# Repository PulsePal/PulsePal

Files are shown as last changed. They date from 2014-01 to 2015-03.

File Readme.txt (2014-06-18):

This is the official repository for Pulse Pal.

Pulse Pal is an open source instrument, released into the public domain under the GNU public license version 3 (see LICENSE.txt).

IMPORTANT: This license means that you can build and modify the device for your own use and even release derivative works commercially, but all derivative versions of the software and hardware MUST remain open source under the GNU license. If you take our code and design files from this repository and sell a derivative design as a closed source commercial product, we will happily sue you.

This repository contains:
-Firmware (written in Arduino / LeafLabs Maple)
-Software APIs in MATLAB, Python and C++
-Drivers (for Windows - none needed for MAC or Linux)
-Design files for the circuit board
-Design files for the enclosure

Documentation is provided online at: 
https://sites.google.com/site/pulsepalwiki/home

The online documentation contains:

-Ordering and assembly guide
-Installation guide
-Programming guides
-Parameter guide
-Serial interface documentation

Please contact us with any questions, bugs, and general feedback:

Joshua Sanders
sanders@cshl.edu

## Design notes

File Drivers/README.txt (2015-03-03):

This driver package for maple was published as part of the open source Arduino_STM32 repository by Roger Clark.
It was inherited in its entirety to provide simple Windows 7, 8 and 8.1 support for Pulse Pal.
To install the drivers, run /PulsePal/drivers/install_drivers.bat.

See more here:
https://github.com/rogerclarkmelbourne

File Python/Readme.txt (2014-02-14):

Note: The PulsePal Python API currently supports Python 2.X only.

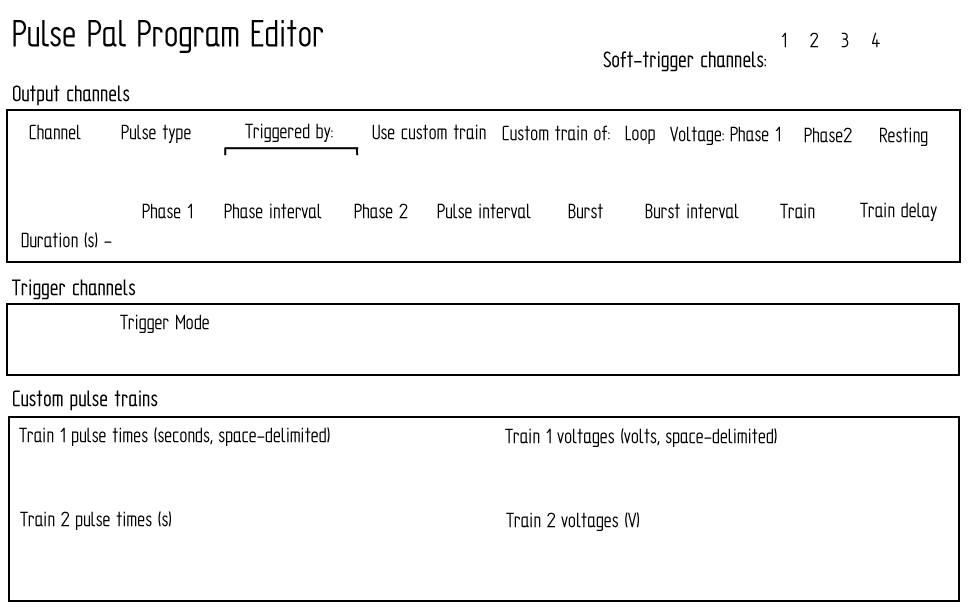
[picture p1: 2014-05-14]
MATLAB/Media/ProgrammerBG.bmp

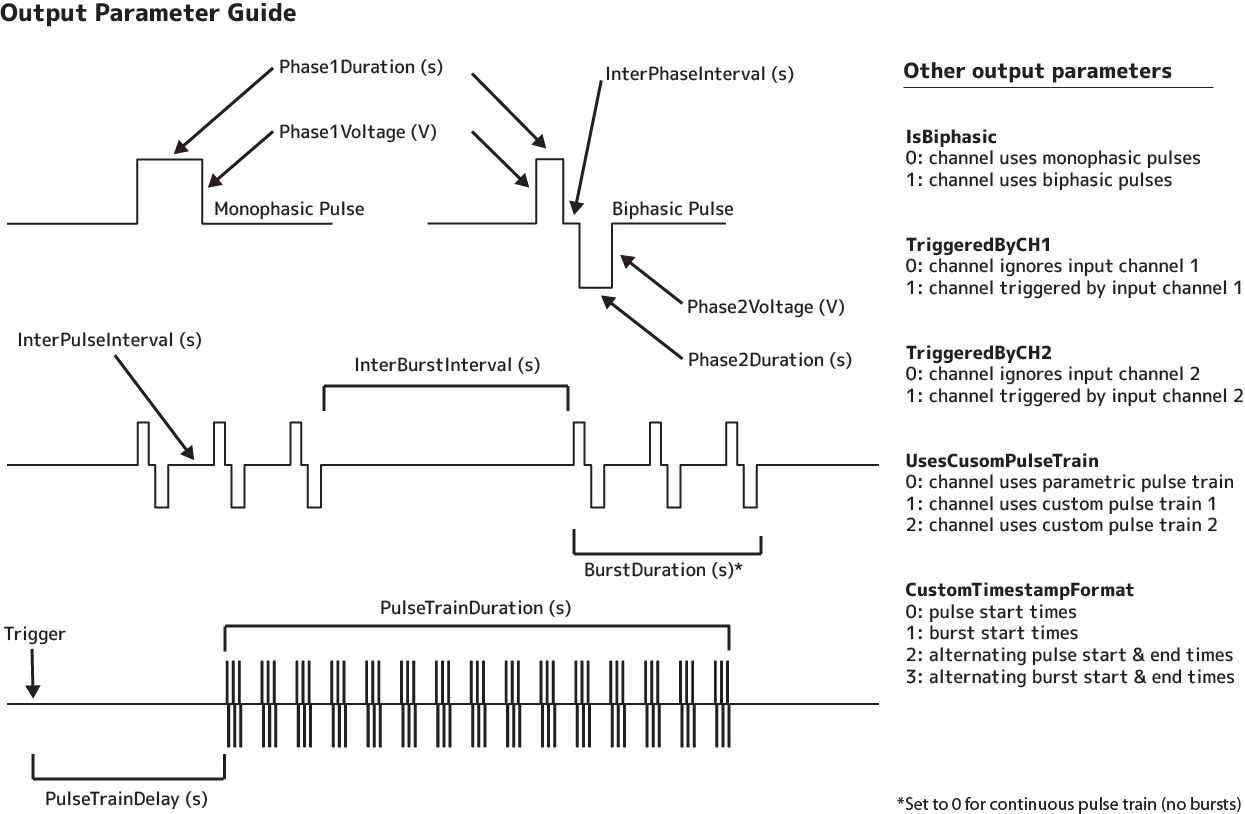
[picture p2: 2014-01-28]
MATLAB/Media/OutputParameterExamples.bmp

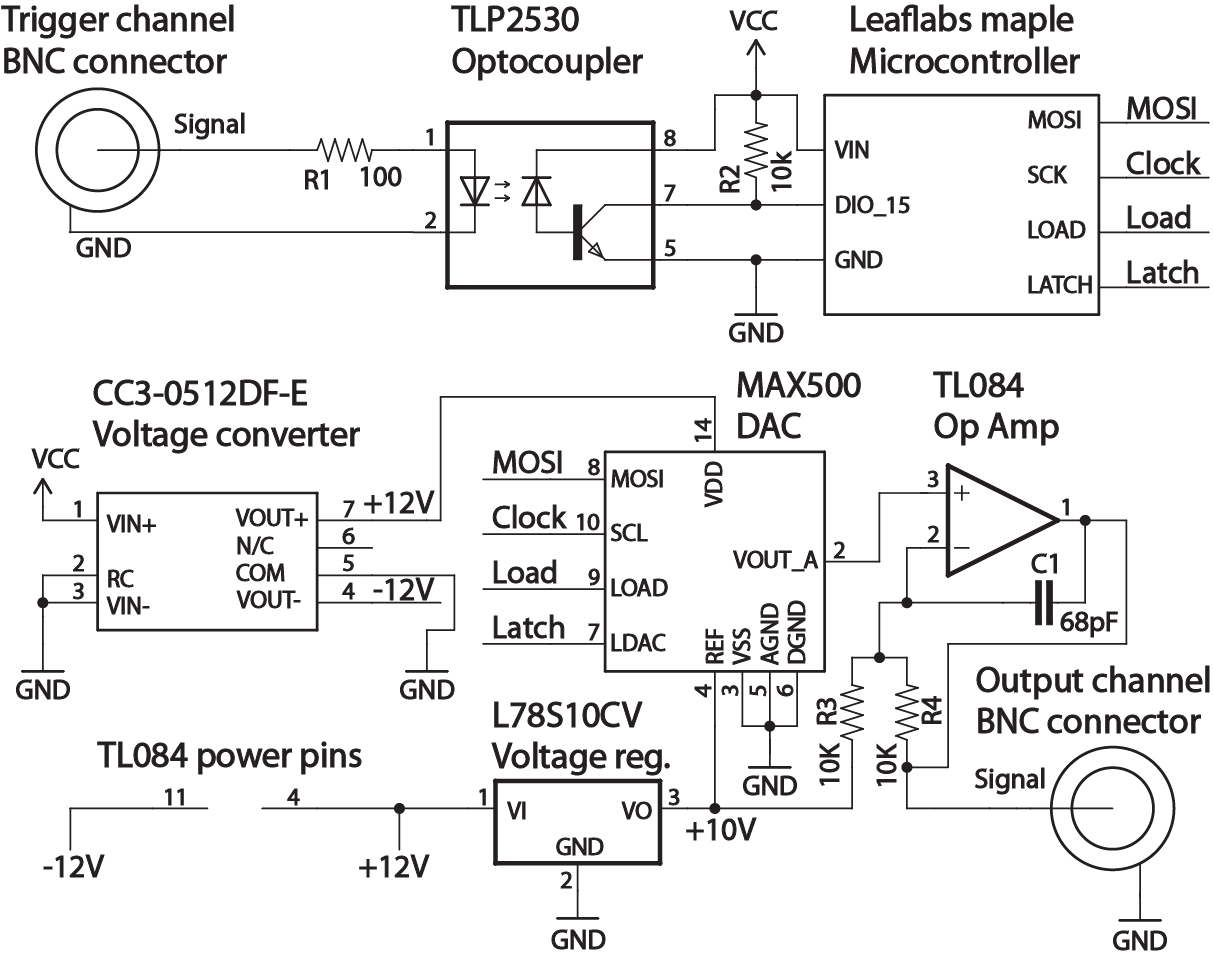
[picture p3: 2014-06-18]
CAD/PCB/r1_0/Essential io circuit.png

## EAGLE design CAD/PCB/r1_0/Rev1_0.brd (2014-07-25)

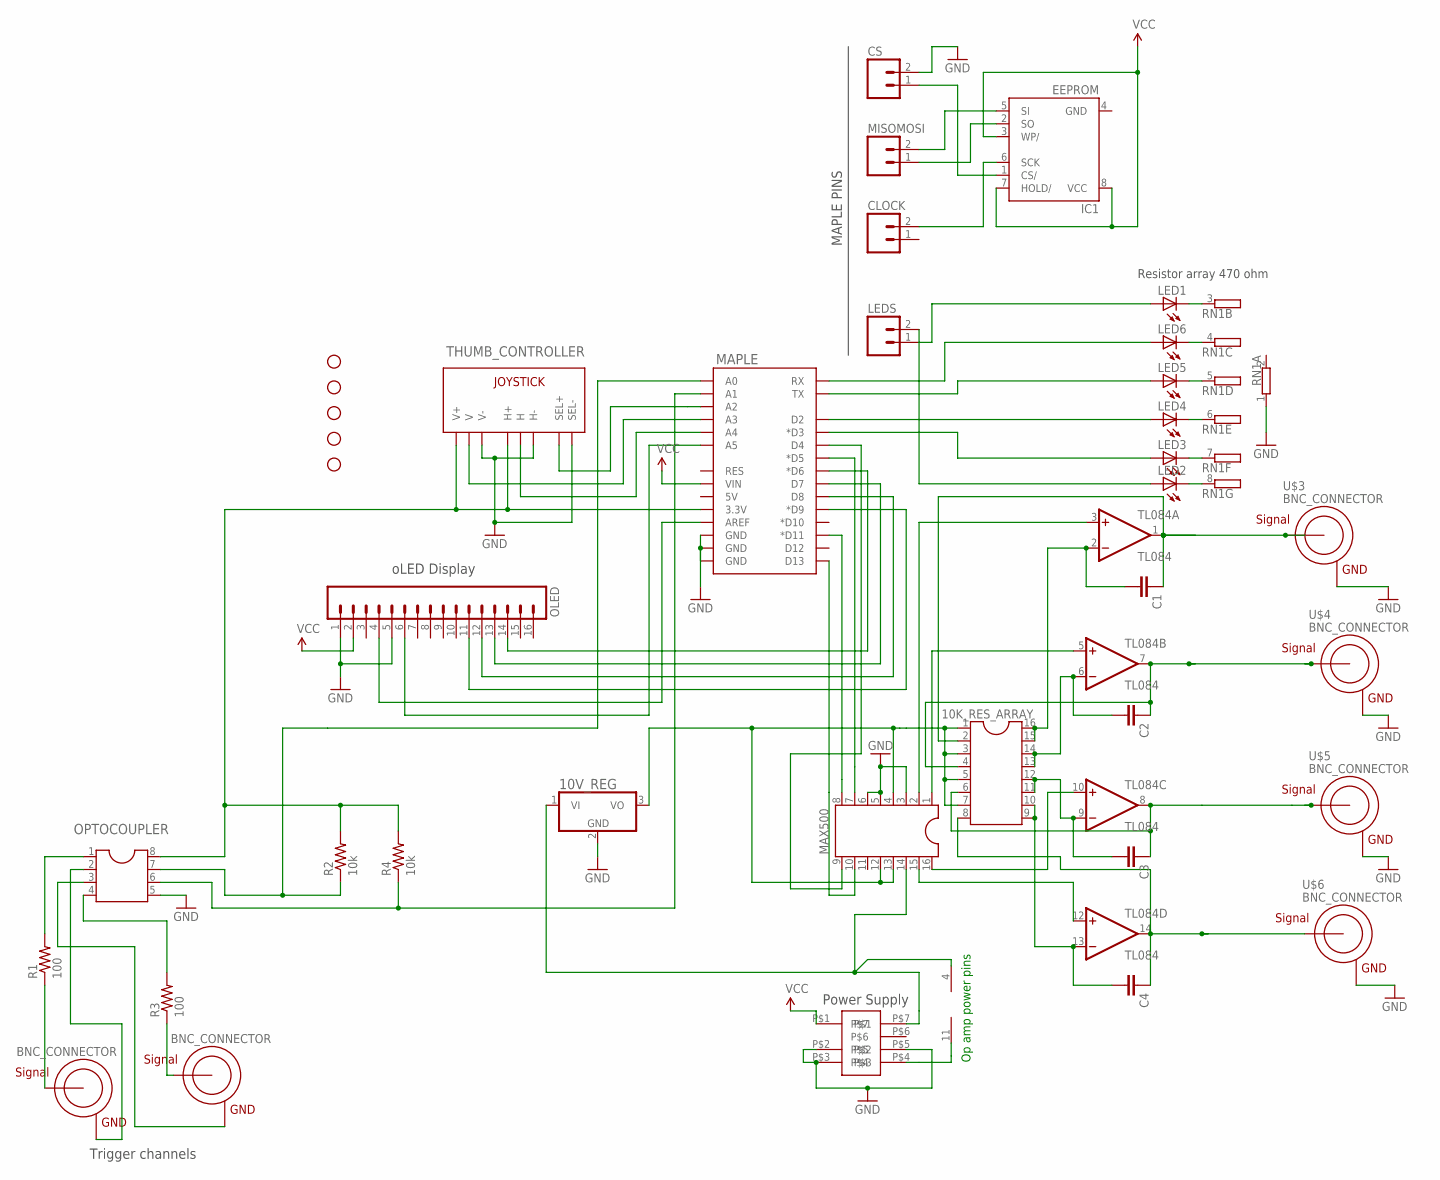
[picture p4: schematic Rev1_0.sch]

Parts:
10K_RES_ARRAY: DIL16
10V_REG: 7805T; TO220H
C1, C2, C3, C4: CAPPTH; CAP-PTH-SMALL
CLOCK: M02PTH; 1X02
CS: M02PTH; 1X02
IC1: EEPROM; DIL08
JP2, JP5, JP6, JP8, JP9: STAND-OFF
LED1, LED2, LED3, LED4, LED5, LED6: LED3MM
LEDS: M02PTH; 1X02
MAPLE: ARDUINO_SHIELDNOHOLESORLABELS; DUEMILANOVE_SHIELD_NOHOLES_NOLABELS
MAX500: DIL16
MISOMOSI: M02PTH; 1X02
OLED: M16PTH; 1X16
OPTOCOUPLER: DIL8; DIL08
R1, R3: 100; AXIAL-0.3
R2, R4: 10k; AXIAL-0.3
RN1: GE07R; SIL8
THUMB_CONTROLLER: JOYSTICKPTH; JOYSTICK
TL084: TL084; DIL14
U$1, U$2, U$3, U$4, U$5, U$6: BNC_CONNECTOR
U$8: TDK_LAMBDA_5_TO_BI_12_125MA

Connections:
GND: 10V_REG.2 (GND), CS.2, IC1.4 (GND), MAPLE.GND@0 (GND), MAPLE.GND@1 (GND), MAPLE.GND@2 (GND), MAX500.3, MAX500.5, MAX500.6, OLED.1, OLED.5, OPTOCOUPLER.5, RN1.1, THUMB_CONTROLLER.B2A (SEL-), THUMB_CONTROLLER.H3 (H-), THUMB_CONTROLLER.V3 (V-), U$3.GND, U$4.GND, U$5.GND, U$6.GND, U$8.P$2, U$8.P$3, U$8.P$5
unnamed: LED6.A, MAPLE.RX
unnamed: LED5.A, MAPLE.TX
unnamed: LED4.A, MAPLE.D2
unnamed: LED3.A, MAPLE.D3 (*D3)
unnamed: MAPLE.D11 (*D11), MAX500.8
unnamed: MAPLE.D13, MAX500.10
unnamed: MAPLE.AREF, OLED.4
unnamed: MAPLE.D4, MAX500.9
unnamed: MAPLE.D5 (*D5), MAX500.7
unnamed: MAPLE.D6 (*D6), OLED.14
unnamed: MAPLE.D7, OLED.13
unnamed: MAPLE.D8, OLED.12
unnamed: MAPLE.D9 (*D9), OLED.11
unnamed: MAPLE.A5, OLED.6
unnamed: MAPLE.A4, THUMB_CONTROLLER.H2 (H)
unnamed: MAPLE.A3, THUMB_CONTROLLER.V2 (V)
unnamed: MAPLE.A2, THUMB_CONTROLLER.B1A (SEL+)
unnamed: R1.P$1 (1), U$1.SIGNAL
unnamed: MAPLE.A0, OPTOCOUPLER.7, R2.P$1 (1)
unnamed: R3.P$1 (1), U$2.SIGNAL
unnamed: MAPLE.A1, OPTOCOUPLER.6, R4.P$1 (1)
unnamed: TL084.11 (V-), U$8.P$4
unnamed: MAX500.2, TL084.3 (+IN)
unnamed: MAX500.1, TL084.5 (+IN)
unnamed: 10V_REG.1 (VI), MAX500.14, TL084.4 (V+), U$8.P$7
unnamed: 10K_RES_ARRAY.1, 10K_RES_ARRAY.3, 10K_RES_ARRAY.5, 10K_RES_ARRAY.7, 10V_REG.3 (VO), MAX500.4, MAX500.12, MAX500.13
unnamed: MAX500.16, TL084.10 (+IN)
unnamed: MAX500.15, TL084.12 (+IN)
unnamed: 10K_RES_ARRAY.2, C1.1, TL084.1 (OUT), U$3.SIGNAL
unnamed: 10K_RES_ARRAY.4, C2.1, TL084.7 (OUT), U$4.SIGNAL
unnamed: 10K_RES_ARRAY.6, C3.1, TL084.8 (OUT), U$5.SIGNAL
unnamed: 10K_RES_ARRAY.8, C4.1, TL084.14 (OUT), U$6.SIGNAL
unnamed: LED1.A, LEDS.1
unnamed: LED2.A, LEDS.2
unnamed: LED2.K (C), RN1.8 (2)
unnamed: LED3.K (C), RN1.7 (2)
unnamed: LED4.K (C), RN1.6 (2)
unnamed: LED5.K (C), RN1.5 (2)
unnamed: LED6.K (C), RN1.4 (2)
unnamed: 10K_RES_ARRAY.15, 10K_RES_ARRAY.16, C1.2, TL084.2 (-IN)
unnamed: 10K_RES_ARRAY.13, 10K_RES_ARRAY.14, C2.2, TL084.6 (-IN)
unnamed: 10K_RES_ARRAY.11, 10K_RES_ARRAY.12, C3.2, TL084.9 (-IN)
unnamed: 10K_RES_ARRAY.9, 10K_RES_ARRAY.10, C4.2, TL084.13 (-IN)
unnamed: LED1.K (C), RN1.3 (2)
unnamed: OPTOCOUPLER.1, R1.P$2 (2)
unnamed: CS.1, IC1.1 (CS/)
unnamed: IC1.5 (SI), MISOMOSI.2
unnamed: IC1.2 (SO), MISOMOSI.1
unnamed: CLOCK.2, IC1.6 (SCK)
unnamed: OPTOCOUPLER.2, U$1.GND
unnamed: OPTOCOUPLER.4, R3.P$2 (2)
unnamed: OPTOCOUPLER.3, U$2.GND
unnamed: MAPLE.3.3V, OPTOCOUPLER.8, R2.P$2 (2), R4.P$2 (2), THUMB_CONTROLLER.H1 (H+), THUMB_CONTROLLER.V1 (V+)
VCC: IC1.3 (WP/), IC1.7 (HOLD/), IC1.8 (VCC), MAPLE.VIN, OLED.2, U$8.P$1

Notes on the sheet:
oLED Display
Power Supply
Op amp power pins
MAPLE PINS
Trigger channels
Resistor array 470 ohm

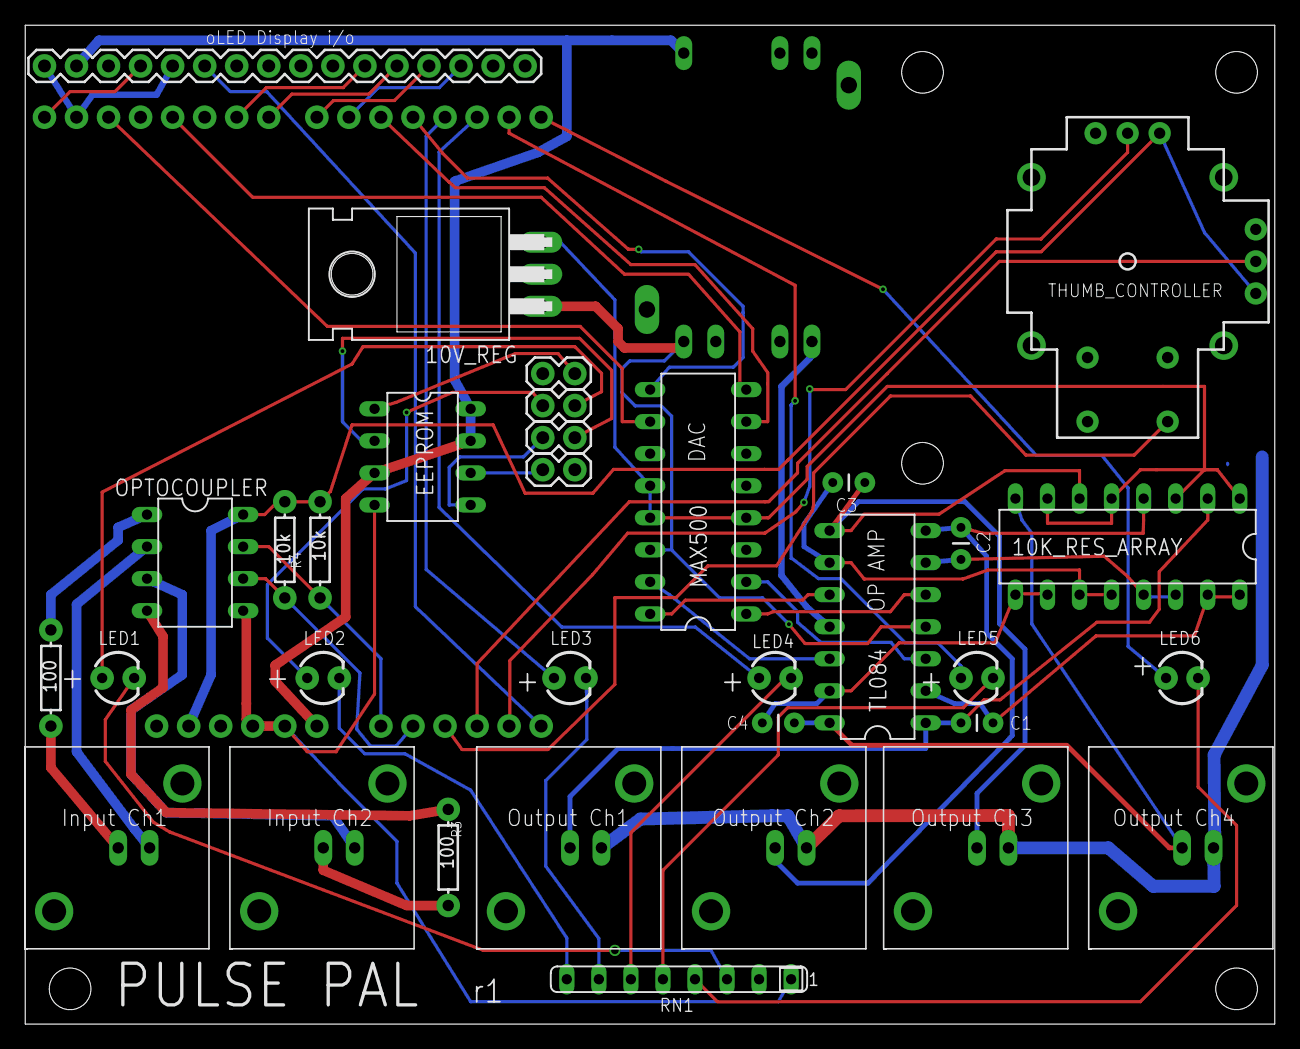
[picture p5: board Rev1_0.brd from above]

Board: 4 copper layers, 99.0 x 79.2 mm, 40 parts (1 on the bottom side), 55 nets.

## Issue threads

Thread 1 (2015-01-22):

Rev1_0_SeeedStudio.zip missing PCB outline file

ksalehi, 2015-01-22:

PulsePal, 2016-01-18:
It should work now.

Closed 2016-01-18.

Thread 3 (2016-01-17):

abort button in matlab GUI

lepmik, 2016-01-17:
It would be nice to be able to stop the current pulse train

PulsePal, 2016-01-18:
You have 4 options for stopping the ongoing pulse train:

1. (stand-alone mode) click the thumb joystick at any time
2. (MATLAB): https://sites.google.com/site/pulsepalwiki/using-pulse-pal/functions/abortpulsepal
3. (Python): https://sites.google.com/site/pulsepalwiki/user-guide---python/python-methods/abortpulsetrains
4: (C++): https://sites.google.com/site/pulsepalwiki/user-guide---c-api/c-methods/abortpulsetrains

Closed 2016-01-18.

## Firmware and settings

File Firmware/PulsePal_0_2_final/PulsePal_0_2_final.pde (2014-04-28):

/*
----------------------------------------------------------------------------

This file is part of the PulsePal Project
Copyright (C) 2014 Joshua I. Sanders, Cold Spring Harbor Laboratory, NY, USA

----------------------------------------------------------------------------

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
*/

// PULSE PAL v0.4 firmware 
// Josh Sanders, March 2012

#include <LiquidCrystal.h>
#include <stdio.h>
#include <gpio.h>

// Define a macro for compressing sequential bytes read from the serial port into long ints
#define makeLong(msb, byte2, byte3, lsb) ((msb << 24) | (byte2 << 16) | (byte3 << 8) | (lsb))
#define LED_PIN_PORT GPIOA
#define INPUT_PIN_PORT GPIOC
// EEPROM constants
#define PAGE_SIZE 32
#define SPI_MODE 0
#define CS 37 // chip select pin
// EEPROM opcodes
#define WREN 6
#define WRDI 4
#define RDSR 5
#define WRSR 1
#define READ 3
#define WRITE 2

// Reset macros
#define SCB_AIRCR ((volatile uint32*) (0xE000ED00 + 0x0C))
#define SCB_AIRCR_SYSRESETREQ (1 << 2)
#define SCB_AIRCR_RESET ((0x05FA0000) | SCB_AIRCR_SYSRESETREQ)

// Trigger line level configuration (0 = default high, trigger low (versions with optocoupler). 1 = default low, trigger high.)
#define TriggerLevel 1
#define ClickerButtonLogicHigh 1


// Firmware build number
unsigned long FirmwareVersion = 2;

// initialize LCD library with the numbers of the interface pins
// Pins matched with hello world LCD sketch
//LiquidCrystal lcd(12, 13, 28, 29, 30, 31);
LiquidCrystal lcd(14, 20, 9, 8, 7, 6);

// Variables that define system parameters
byte InputLines[2] = {15,16};
byte InputLineBits[2] = {0,1};
byte OutputLEDLines[4] = {3,2,1,0}; // Output lines
byte OutputLEDLineBits[4] = {1, 0, 2, 3 }; // for faster write times, "Bits" address the pins directly - low level ARM commands.
byte InputLEDLines[2] = {35, 36};
byte InputLEDLineBits[2] = {6,7}; 
byte ClickerXLine = 19;
byte ClickerYLine = 18;
byte ClickerButtonLine = 17;
byte ClickerButtonBit = 2;
//int ClickerButtonSupplyPin = 6;
//int HbridgeEnableLine = 12; // tie to vcc in future editions
byte LEDLine = 22;
byte DACLoadPin=4;
byte DACLatchPin=5;
byte USBPacketCorrectionByte = 0; // If messages sent over USB in Windows XP are 64 bytes, the system crashes - so this variable keeps track of whether to chop off a junk byte at the end of the message. Used for custom stimuli.
HardwareSPI spi(1);
HardwareSPI EEPROM(2);
byte CycleDuration = 100;
byte HalfCycle = CycleDuration/2;

// Variables related to EEPROM
byte PageBytes[32] = {0}; // Stores page to be written
int EEPROM_address = 0;
byte EEPROM_OutputValue = 0;
byte nBytesToWrite = 0;
byte nBytesToRead = 0;
byte BrokenBytes[4] = {0};

// Variables that define pulse trains currently loaded on the 4 output channels
unsigned long Phase1Duration[4] = {0};
unsigned long InterPhaseInterval[4] = {0};
unsigned long Phase2Duration[4] = {0};
unsigned long InterPulseInterval[4] = {0};
unsigned long BurstDuration[4] = {0};
unsigned long BurstInterval[4] = {0};
unsigned long PulseTrainDuration[4] = {0};
unsigned long PulseTrainDelay[4] = {0};
int CustomTrainID[4] = {0}; // If 0, uses above params. If 1 or 2, triggering plays back timestamps in CustomTrain1 or CustomTrain2 with pulsewidth defined as usual
int CustomTrainTarget[4] = {0}; // If 0, custom stim timestamps are start-times of pulses. If 1, custom stim timestamps are start-times of bursts.
int CustomTrainLoop[4] = {0}; // if 0, custom stim plays once. If 1, custom stim loops until PulseTrainDuration.
int ConnectedToApp = 0; // 0 for none, 1 for MATLAB client, 2 for Labview client, 3 for Python client

// Variables used in programming
byte TriggerAddress[2][4] = {0}; // This specifies which output channels get triggered by trigger channel 1 (row 1) or trigger channel 2 (row 2)
byte TriggerMode[2] = {0}; // if 0, "Normal mode", triggers on low to high transitions and ignores triggers until end of stimulus train. if 1, "Toggle mode", triggers on low to high and shuts off stimulus
//train on next high to low. If 2, "Button mode", triggers on low to high and shuts off on high to low.
unsigned long TriggerButtonDebounce[2] = {0}; // In button mode, number of microseconds the line must be low before stopping the pulse train.
int CustomPulseTimeIndex[4] = {0}; // Keeps track of the pulse number being played in custom stim condition
unsigned long CustomTrainNpulses[2] = {0}; // Number of pulses in the stimulus
byte Phase1Voltage[4] = {0};
byte Phase2Voltage[4] = {0};
int ClickerX = 0; // Value of analog reads from X line of joystick input device
int ClickerY = 0; // Value of analog reads from Y line of joystick input device
boolean ClickerButtonState = 0; // Value of digital reads from button line of joystick input device
boolean LastClickerButtonState = 1;
int LastClickerYState = 0; // 0 for neutral, 1 for up, 2 for down.
int LastClickerXState = 0; // 0 for neutral, 1 for left, 2 for right.
int inMenu = 0; // Menu id: 0 for top, 1 for channel menu, 2 for action menu
int SelectedChannel = 0;
int SelectedAction = 1;
byte SelectedInputAction = 1;
int SelectedStimMode = 1;
boolean NeedUpdate = 0; // If a new menu item is selected, the screen must be updated
boolean SerialReadTimedout = 0; // Goes to 1 if a serial read timed out, causing all subsequent serial reads to skip until next main loop iteration.
int SerialCurrentTime = 0; // Current time (millis) for serial read timeout
int SerialReadStartTime = 0; // Time the serial read was started
byte Timeout = 200; // Times out after 200ms

// Variables used in stimulus playback
byte inByte; byte inByte2; byte inByte3; byte inByte4; byte CommandByte;
byte LogicLevel = 0;
unsigned long SystemTime = 0; // Number of cycles since stimulation start
unsigned long MicrosTime = 0; // Actual system time (microseconds from boot, wraps over every 72m
unsigned long BurstTimestamps[4] = {0};
unsigned long PrePulseTrainTimestamps[4] = {0};
unsigned long PulseTrainTimestamps[4] = {0};
unsigned long NextPulseTransitionTime[4] = {0}; // Stores next pulse-high or pulse-low timestamp for each channel
unsigned long NextBurstTransitionTime[4] = {0}; // Stores next burst-on or burst-off timestamp for each channel
unsigned long StimulusTrainEndTime[4] = {0}; // Stores time the stimulus train is supposed to end
unsigned long CustomPulseTimes[2][1001] = {0};
byte CustomVoltages[2][1001] = {0};
unsigned long LastLoopTime = 0;
boolean PulseStatus[4] = {0}; // This is 0 if not delivering a pulse, 1 if delivering.
boolean BurstStatus[4] = {0}; // This is "true" during bursts and false during inter-burst intervals.
boolean StimulusStatus[4] = {0}; // This is "true" for a channel when the stimulus train is actively being delivered
boolean PreStimulusStatus[4] = {0}; // This is "true" for a channel during the pre-stimulus delay
boolean InputValues[2] = {0}; // The values read directly from the two inputs (for analog, digital equiv. after thresholding)
boolean InputValuesLastCycle[2] = {0}; // The values on the last cycle. Used to detect low to high transitions.
boolean LineTriggerEvent[2] = {0}; // 0 if no line trigger event detected, 1 if present.
unsigned long InputLineDebounceTimestamp[2] = {0}; // Last time the line went from high to low
boolean UsesBursts[4] = {0};
boolean IsBiphasic[4] = {0};
boolean ContinuousLoopMode[4] = {0}; // If true, the channel loops its programmed stimulus train continuously
int AnalogValues[2] = {0};
int SensorValue = 0;
boolean Stimulating = 0; // true if ANY channel is stimulating. Used to shut down analog reads on joystick, USB com, etc. for increased precision.
boolean WasStimulating = 0; // true if any channel was stimulating on the previous loop. Used to force a DAC write after all channels end their stimulation, to return lines to 0
int nStimulatingChannels = 0; // number of actively stimulating channels
boolean DACFlags[4] = {0}; // true if an individual DAC needs to be updated
byte DACValues[4] = {0};
byte DefaultInputLevel = 0; // 0 for PulsePal 0.3, 1 for 0.2 and 0.1. Logic is inverted by optoisolator
byte DACBuffer0[2] = {0}; // Buffers already containing address for faster SPIwriting
byte DACBuffer1[2] = {1};
byte DACBuffer2[2] = {2};
byte DACBuffer3[2] = {3};

// Other variables
char Value2Display[18] = {' ', ' ', ' ', ' ', ' ', ' ', ' ', ' ', ' ', ' ', ' ', ' ', ' ', ' ', ' ', ' ', '\0'};
int lastDebounceTime = 0; // to debounce the joystick button
boolean lastButtonState = 0;
boolean ChoiceMade = 0; // determines whether user has chosen a value from a list
unsigned int UserValue = 0; // The current value displayed on a list of values (written to LCD when choosing parameters)
char CommanderString[16] = " PULSE PAL v0.2";
char ClientStringSuffix[11] = " Connected";
char DefaultCommanderString[16] = " PULSE PAL v0.2";
byte ValidEEPROMProgram = 0; // A byte read from EEPROM. This is always 1 if the EEPROM has been written to. Used to load defaults on first-time use.

void setup() {
  // Enable EEPROM
  pinMode(CS, OUTPUT);
  digitalWrite(CS, HIGH); // disable writes
  EEPROM.begin(SPI_9MHZ, MSBFIRST, SPI_MODE);
  // set up the LCD
  lcd.begin(16, 2);
  lcd.clear();
  lcd.home();
  lcd.noDisplay() ;
  delay(100);
  lcd.display() ;
  
  // Pin modes
  pinMode(InputLines[0], INPUT);
  pinMode(InputLines[1], INPUT);
  pinMode(ClickerButtonLine, INPUT_PULLUP);
  pinMode(ClickerXLine, INPUT_ANALOG);
  pinMode(ClickerYLine, INPUT_ANALOG);
  
    for (int x = 0; x < 4; x++) {
    pinMode(OutputLEDLines[x], OUTPUT);
  }
    spi.begin(SPI_18MHZ, MSBFIRST, 0);
    pinMode(DACLoadPin, OUTPUT);
    pinMode(DACLatchPin, OUTPUT);
    pinMode(InputLEDLines[0], OUTPUT);
    pinMode(InputLEDLines[1], OUTPUT);
    // Set DAC to 0V on all channels
    digitalWrite(DACLoadPin,HIGH);
    digitalWrite(DACLatchPin, HIGH);
    for (int x = 0; x < 4; x++) {
      spi.write(x);
      spi.write(128);
      digitalWrite(DACLoadPin, LOW);
      digitalWrite(DACLoadPin, HIGH);
      DACValues[x] = 128;
    }
    //---end Set DAC
  
    digitalWrite(DACLatchPin,LOW);
    digitalWrite(DACLatchPin, HIGH); 
    RestoreParametersFromEEPROM();
    if (ValidEEPROMProgram != 1) {
      LoadDefaultParameters();
    }
    RestoreCustomStimuli();
    write2Screen(CommanderString," Click for menu");
    SystemTime = micros();
    LastLoopTime = SystemTime;
    DefaultInputLevel = 1 - TriggerLevel;
}

void loop() {
  if (SerialReadTimedout == 1) {
    HandleReadTimeout(); // Notifies user of error, then prompts to click and restores DEFAULT channel settings.
    SerialReadTimedout = 0;
  }
  if (Stimulating == 0) {
      MicrosTime = micros();
      UpdateSettingsMenu(inByte);
      SystemTime = 0;
   } else {
     while ((MicrosTime-LastLoopTime) < CycleDuration) {  // Make sure loop runs once every 100us 
         MicrosTime = micros();
      } 
     dacWrite(DACValues); // Update DAC
     SystemTime++; // Increment system time (# of cycles since stim start)
     ClickerButtonState = digitalRead(ClickerButtonLine);
     if (ClickerButtonState == ClickerButtonLogicHigh){    // A button click ends ongoing stimulation on all channels.
       AbortAllPulseTrains();
     }
  }
  LastLoopTime = MicrosTime;
      
  if (SerialUSB.available() > 0) {
    CommandByte = SerialUSB.read();
    switch (CommandByte) {
      case 72: { // Handshake
        SerialUSB.write(75); // Send 'K' (as in ok)
        breakLong(FirmwareVersion); // Send 32-bit firmware version
        SerialUSB.write(BrokenBytes[0]);
        SerialUSB.write(BrokenBytes[1]);
        SerialUSB.write(BrokenBytes[2]);
        SerialUSB.write(BrokenBytes[3]); 
        ConnectedToApp = 1;
      } break;
      case 73: { // Program the module - total program (faster than item-wise in some instances)
        for (int x = 0; x < 4; x++) {
          Phase1Duration[x] = SerialReadLong();
          InterPhaseInterval[x] = SerialReadLong();
          Phase2Duration[x] = SerialReadLong();
          InterPulseInterval[x] = SerialReadLong();
          BurstDuration[x] = SerialReadLong();
          BurstInterval[x] = SerialReadLong();
          PulseTrainDuration[x] = SerialReadLong();
          PulseTrainDelay[x] = SerialReadLong();
        }
        for (int x = 0; x < 4; x++) {
          IsBiphasic[x] = SerialReadByte();
          Phase1Voltage[x] = SerialReadByte();
          Phase2Voltage[x] = SerialReadByte();
          CustomTrainID[x] = SerialReadByte();
          CustomTrainTarget[x] = SerialReadByte();
          CustomTrainLoop[x] = SerialReadByte();
        }
       for (int x = 0; x < 2; x++) { // Read 8 trigger address bytes
         for (int y = 0; y < 4; y++) {
           TriggerAddress[x][y] = SerialReadByte();
         }
       }
       TriggerMode[0] = SerialReadByte(); 
       TriggerMode[1] = SerialReadByte();
       SerialUSB.write(1); // Send confirm byte
       for (int x = 0; x < 4; x++) {
         if ((BurstDuration[x] == 0) || (BurstInterval[x] == 0)) {UsesBursts[x] = false;} else {UsesBursts[x] = true;}
         if (CustomTrainTarget[x] == 1) {UsesBursts[x] = true;}
         if ((CustomTrainID[x] > 0) && (CustomTrainTarget[x] == 0)) {UsesBursts[x] = false;}
       }
      } break;
      
      // Program the module - one parameter
      case 74: {
        inByte2 = SerialReadByte();
        inByte3 = SerialReadByte(); // inByte3 = channel (1-4)
        inByte3 = inByte3 - 1; // Convert channel for zero-indexing
        switch (inByte2) { 
           case 1: {IsBiphasic[inByte3] = SerialReadByte();} break;
           case 2: {Phase1Voltage[inByte3] = SerialReadByte();} break;
           case 3: {Phase2Voltage[inByte3] = SerialReadByte();} break;
           case 4: {Phase1Duration[inByte3] = SerialReadLong();} break;
           case 5: {InterPhaseInterval[inByte3] = SerialReadLong();} break;
           case 6: {Phase2Duration[inByte3] = SerialReadLong();} break;
           case 7: {InterPulseInterval[inByte3] = SerialReadLong();} break;
           case 8: {BurstDuration[inByte3] = SerialReadLong();} break;
           case 9: {BurstInterval[inByte3] = SerialReadLong();} break;
           case 10: {PulseTrainDuration[inByte3] = SerialReadLong();} break;
           case 11: {PulseTrainDelay[inByte3] = SerialReadLong();} break;
           case 12: {inByte4 = SerialReadByte(); TriggerAddress[0][inByte3] = inByte4;} break;
           case 13: {inByte4 = SerialReadByte(); TriggerAddress[1][inByte3] = inByte4;} break;
           case 14: {CustomTrainID[inByte3] = SerialReadByte();} break;
           case 15: {CustomTrainTarget[inByte3] = SerialReadByte();} break;
           case 16: {CustomTrainLoop[inByte3] = SerialReadByte();} break;
           case 128: {TriggerMode[inByte3] = SerialReadByte();} break;
        }
        if (inByte2 < 14) {
          if ((BurstDuration[inByte3] == 0) || (BurstInterval[inByte3] == 0)) {UsesBursts[inByte3] = false;} else {UsesBursts[inByte3] = true;}
          if (CustomTrainTarget[inByte3] == 1) {UsesBursts[inByte3] = true;}
          if ((CustomTrainID[inByte3] > 0) && (CustomTrainTarget[inByte3] == 0)) {UsesBursts[inByte3] = false;}
        }
        SerialUSB.write(1); // Send confirm byte
      } break;

      // Program custom stimulus 1
      case 75: {
        digitalWrite(LEDLine, HIGH); //
        USBPacketCorrectionByte = SerialReadByte();
        CustomTrainNpulses[0] = SerialReadLong();
        for (int x = 0; x < CustomTrainNpulses[0]; x++) {
          CustomPulseTimes[0][x] = SerialReadLong();
        }
        for (int x = 0; x < CustomTrainNpulses[0]; x++) {
          CustomVoltages[0][x] = SerialReadByte();
        }
        if (USBPacketCorrectionByte == 1) {
          USBPacketCorrectionByte = 0;
          CustomTrainNpulses[0] = CustomTrainNpulses[0]  - 1;
        }
        SerialUSB.write(1); // Send confirm byte
        digitalWrite(LEDLine, LOW); //
      } break;
      // Program custom stimulus 2
      case 76: {
        digitalWrite(LEDLine, HIGH); //
        USBPacketCorrectionByte = SerialReadByte();
        CustomTrainNpulses[1] = SerialReadLong();
        for (int x = 0; x < CustomTrainNpulses[1]; x++) {
          CustomPulseTimes[1][x] = SerialReadLong();
        }
        for (int x = 0; x < CustomTrainNpulses[1]; x++) {
          CustomVoltages[1][x] = SerialReadByte();
        }
        if (USBPacketCorrectionByte == 1) {
          USBPacketCorrectionByte = 0;
          CustomTrainNpulses[1] = CustomTrainNpulses[1]  - 1;
        }
        SerialUSB.write(1); // Send confirm byte
        digitalWrite(LEDLine, LOW); //
      } break;      
      // Soft-trigger the module
      case 77: {
        inByte2 = SerialReadByte();
        for (int x = 0; x < 4; x++) {
          PreStimulusStatus[x] = bitRead(inByte2, x);
          if (PreStimulusStatus[x] == 1) {
            if ((CustomTrainID[x] != 0) && (CustomTrainTarget[x] == 1)) {BurstStatus[x] = 0;} else {
                 BurstStatus[x] = 1; 
            }
          if (Stimulating == 0) {ResetSystemTime();}
            PrePulseTrainTimestamps[x] = SystemTime;
          }
        }
      } break;
      case 78: { 
        lcd.clear();
         lcd.home(); 
         byte ByteCount = 0;
        // read all the available characters
        inByte2 = SerialReadByte(); // Total length of message to follow (including newline)
        while (ByteCount < inByte2) {
            // display each character to the LCD
            inByte = SerialReadByte();
            if (inByte != 254) {
              lcd.write(inByte);
            } else {
              lcd.setCursor(0, 1);
            }
            ByteCount++;
        }
      } break;
      case 79: {
        // Write specific voltage to output channel (not a pulse train) 
        inByte = SerialReadByte();
        inByte = inByte - 1; // Convert for zero-indexing
        inByte2 = SerialReadByte();
        DACValues[inByte] = inByte2;
        dacWrite(DACValues);
        SerialUSB.write(1); // Send confirm byte
      } break;
      case 80: { // Soft-abort ongoing stimulation without disconnecting from client
       for (int x = 0; x < 4; x++) {
        killChannel(x);
      }
      dacWrite(DACValues);
     } break;
     case 81: { // Disconnect from client and store params to EEPROM
        ConnectedToApp = 0;
        inMenu = 0;
        for (int x = 0; x < 4; x++) {
          killChannel(x);
        }
        dacWrite(DACValues);
        // Store last program to EEPROM
        write2Screen("Saving Settings",".");
        EEPROM_address = 0;
        for (int x = 0; x < 4; x++) {
          PrepareOutputChannelMemoryPage1(x);
          WriteEEPROMPage(PageBytes, 32, EEPROM_address);
          EEPROM_address = EEPROM_address + 32;
          PrepareOutputChannelMemoryPage2(x);
          WriteEEPROMPage(PageBytes, 32, EEPROM_address);
          EEPROM_address = EEPROM_address + 32;
          switch (x) {
            case 0: { write2Screen("Saving Settings",". .");} break;
            case 1: { write2Screen("Saving Settings",". . .");} break;
            case 2: { write2Screen("Saving Settings",". . . .");} break;
            case 3: { write2Screen("Saving Settings",". . . . .");} break;
          }
          delay(100);
        }
        write2Screen("Saving Settings",". . . . . Done!");
        delay(700);
        for (int x = 0; x < 16; x++) {
         CommanderString[x] = DefaultCommanderString[x];
       } 
        write2Screen(CommanderString," Click for menu");
       } break;
       // Set free-run mode
      case 82:{
        inByte2 = SerialReadByte();
        inByte2 = inByte2 - 1; // Convert for zero-indexing
        inByte3 = SerialReadByte();
        ContinuousLoopMode[inByte2] = inByte3;
        SerialUSB.write(1);
      } break;
      case 83: { // Clear stored parameters from EEPROM
       WipeEEPROM();
       if (inMenu == 0) {
        write2Screen(CommanderString," Click for menu");
      } else {
        inMenu = 1;
        RefreshChannelMenu(SelectedChannel);
      }
     } break;
     case 84: {
        inByte2 = SerialReadByte();
        EEPROM_address = inByte2;
        nBytesToWrite = SerialReadByte();
        for (int i = 0; i < nBytesToWrite; i++) {
        PageBytes[i] = SerialReadByte();
        }
        WriteEEPROMPage(PageBytes, nBytesToWrite, EEPROM_address);
        SerialUSB.write(1);
      } break; 
    case 85: {
        inByte2 = SerialReadByte();
        EEPROM_address = inByte2;
        nBytesToRead = SerialReadByte();
        for (int i = 0; i < nBytesToRead; i++) {
         EEPROM_OutputValue = ReadEEPROM(EEPROM_address+i);
         SerialUSB.write(EEPROM_OutputValue);
        }
      } break;
      
      case 86: { // Override IO Lines
        inByte2 = SerialReadByte();
        inByte3 = SerialReadByte();
        pinMode(inByte2, OUTPUT); digitalWrite(inByte2, inByte3);
      } break; 
      
      case 87: { // Direct Read IO Lines
        inByte2 = SerialReadByte();
        pinMode(inByte2, INPUT);
        delayMicroseconds(10);
        LogicLevel = digitalRead(inByte2);
        SerialUSB.write(LogicLevel);
      } break; 
      case 88: { // Direct Read IO Lines as analog
        inByte2 = SerialReadByte();
        pinMode(inByte2, INPUT_ANALOG);
        delay(10);
        SensorValue = analogRead(inByte2);
        SerialUSB.println(SensorValue);
        pinMode(inByte2, OUTPUT);
      } break;
      case 89: { // Receive new CommanderString (displayed on top line of OLED, i.e. "MATLAB connected"
        for (int x = 0; x < 6; x++) {
          CommanderString[x] = SerialReadByte();
        }
        for (int x = 6; x < 16; x++) {
          CommanderString[x] = ClientStringSuffix[x-6];
        }
        write2Screen(CommanderString," Click for menu");
      } break;
     }
   }
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

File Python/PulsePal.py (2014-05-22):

'''
----------------------------------------------------------------------------

This file is part of the PulsePal Project
Copyright (C) 2014 Joshua I. Sanders, Cold Spring Harbor Laboratory, NY, USA

----------------------------------------------------------------------------

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
You should have received a copy of the GNU General Public License
along with this program.  If not, see <http://www.gnu.org/licenses/>.
'''

import struct
import math

class PulsePalObject(object):
    
    def __init__(self):
        self.serialObject = 0
        self.OpMenuByte = 213
        self.firmwareVersion = 0
        self.cycleFrequency = 20000;
        self.isBiphasic = [0]*5;
        self.phase1Voltage = [5]*5;
        self.phase2Voltage = [-5]*5;
        self.restingVoltage = [0]*5;
        self.phase1Duration = [0.001]*5;
        self.interPhaseInterval = [0.001]*5;
        self.phase2Duration = [0.001]*5;
        self.interPulseInterval = [0.01]*5;
        self.burstDuration = [0]*5;
        self.interBurstInterval = [0]*5;
        self.pulseTrainDuration = [1]*5;
        self.pulseTrainDelay = [0]*5;
        self.linkTriggerChannel1 = [1]*5;
        self.linkTriggerChannel2 = [0]*5;
        self.customTrainID = [0]*5;
        self.customTrainTarget = [0]*5;
        self.customTrainLoop = [0]*5;
        self.triggerMode = [0]*3;
        self.outputParameterNames = ['isBiphasic', 'phase1Voltage','phase2Voltage', 'phase1Duration', 'interPhaseInterval', 
                               'phase2Duration','interPulseInterval', 'burstDuration', 'interBurstInterval', 'pulseTrainDuration', 
                               'pulseTrainDelay', 'linkTriggerChannel1', 'linkTriggerChannel2', 'customTrainID', 
                               'customTrainTarget', 'customTrainLoop', 'restingVoltage']
        self.triggerParameterNames = ['triggerMode']
        
    def connect(self, serialPortName):
        import serial
        self.serialObject = serial.Serial(serialPortName, 115200)
        handshakeByteString = struct.pack('BB', self.OpMenuByte, 72)
        self.serialObject.write(handshakeByteString)
        Response = self.serialObject.read(5)
        fvBytes = Response[1:5]
        self.firmwareVersion = struct.unpack('<I',fvBytes)[0]
        self.serialObject.write('YPYTHON')
        
    def disconnect(self):
        terminateByteString = struct.pack('BB', self.OpMenuByte, 81)
        self.serialObject.write(terminateByteString)
        self.serialObject.close()
        
    def programOutputChannelParam(self, paramName, channel, value):
        originalValue = value
        if isinstance(paramName, basestring):
            paramCode = self.outputParameterNames.index(paramName)+1
        else:
            paramCode = paramName
        
        if 2 <= paramCode <= 3:
            value = math.ceil(((value+10)/float(20))*255) # Convert volts to bits
        if paramCode == 17:
            value = math.ceil(((value+10)/float(20))*255) # Convert volts to bits
        if 4 <= paramCode <= 11:
            programByteString = struct.pack('<BBBBL',self.OpMenuByte,74,paramCode,channel,value*self.cycleFrequency)
        else:
            programByteString = struct.pack('BBBBB',self.OpMenuByte,74,paramCode,channel,value)
        self.serialObject.write(programByteString)
        # Update the PulsePal object's parameter fields
        if paramCode == 1:
            self.isBiphasic[channel] = originalValue
        elif paramCode == 2:
            self.phase1Voltage[channel] = originalValue
        elif paramCode == 3:  
            self.phase2Voltage[channel] = originalValue 
        elif paramCode == 4:
            self.phase1Duration[channel] = originalValue
        elif paramCode == 5:
            self.interPhaseInterval[channel] = originalValue
        elif paramCode == 6:
            self.phase2Duration[channel] = originalValue
        elif paramCode == 7:
            self.interPulseInterval[channel] = originalValue
        elif paramCode == 8:
            self.burstDuration[channel] = originalValue
        elif paramCode == 9:
            self.interBurstInterval[channel] = originalValue
        elif paramCode == 10:
            self.pulseTrainDuration[channel] = originalValue
        elif paramCode == 11:
            self.pulseTrainDelay[channel] = originalValue
        elif paramCode == 12:
            self.linkTriggerChannel1[channel] = originalValue
        elif paramCode == 13:
            self.linkTriggerChannel2[channel] = originalValue
        elif paramCode == 14:
            self.customTrainID[channel] = originalValue
        elif paramCode == 15:
            self.customTrainTarget[channel] = originalValue
        elif paramCode == 16:  
            self.customTrainLoop[channel] = originalValue 
        elif paramCode == 17:  
            self.restingVoltage[channel] = originalValue 
            
    def programTriggerChannelParam(self, paramName, channel, value):
        originalValue = value
        if isinstance(paramName, basestring):
            paramCode = self.triggerParameterNames.index(paramName)+1
        else:
            paramCode = paramName
        messageBytes = struct.pack('BBBBB',self.OpMenuByte, 74,paramCode,channel,value)
        self.serialObject.write(messageBytes)    
        if paramCode == 1:
            self.triggerMode[channel] = originalValue
            
    def syncAllParams(self):
        # First make a list data-type with all param values in an iteration of the loop.
        # Then pack them by data-type and append to string with + operation
        programByteString = struct.pack('BB',self.OpMenuByte, 73)
        
        # Add 32-bit time params
        programValues = [0]*32; pos = 0
        for i in range(1,5):
            programValues[pos] = self.phase1Duration[i]*self.cycleFrequency; pos+=1
            programValues[pos] = self.interPhaseInterval[i]*self.cycleFrequency; pos+=1
            programValues[pos] = self.phase2Duration[i]*self.cycleFrequency; pos+=1
            programValues[pos] = self.interPulseInterval[i]*self.cycleFrequency; pos+=1
            programValues[pos] = self.burstDuration[i]*self.cycleFrequency; pos+=1
            programValues[pos] = self.interBurstInterval[i]*self.cycleFrequency; pos+=1
            programValues[pos] = self.pulseTrainDuration[i]*self.cycleFrequency; pos+=1
            programValues[pos] = self.pulseTrainDelay[i]*self.cycleFrequency; pos+=1
        # Pack 32-bit times to bytes and append to program byte-string
        programByteString = programByteString + struct.pack('<LLLLLLLLLLLLLLLLLLLLLLLLLLLLLLLL' , *programValues)
        
        # Add 8-bit params
        programValues = [0]*28; pos = 0
        for i in range(1,5):
            programValues[pos] = self.isBiphasic[i]; pos+=1
            value = math.ceil(((self.phase1Voltage[i]+10)/float(20))*255) # Convert volts to bits
            programValues[pos] = value; pos+=1
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

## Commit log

2014-02-04 -Added pulse-gate functionality to trigger channels -Added new c++ API (tested, working) -Made parameter names in MATLAB, firmware and c++ consistent with parameter names on wiki. -Partially solved c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
    [PulsePal_0_4.pde]
2014-02-04 -Fixed custom pulse train bug causing short first pulse. -Bug: First pulse of custom loop is still 50us
    [PulsePal_0_4.pde]
2014-02-04 -Fixed first pulse of custom loop problem by setting Pulse Pal's cycle duration to 100us instead of 50us. -Added parameter in MATLAB client, which uses firmware version returned during handshake to d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
    [PulsePal_0_4.pde]
2014-02-10 Fixed version numbers in 0_2 and 0_3 firmware Fixed precision limit for joystick time parameter entry in 0_2 and 0_3 firmware
    [PulsePal_0_2_final.pde, PulsePal_0_3_final.pde]
2014-02-13 -Added license to each script -Updated syntax for sending custom pulse trains in C++ API to match MATLAB API -Added revised PCB design files to account for longer op amp package (TI replaces ST micro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
    [Rev0_4.brd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]
2014-02-26 Added pre-zipped GERBER for easy PCB ordering Added a MATLAB convenience function to make sine waves in phase, for custom waveform looping
2014-03-06 Changed output channel series resistors in CAD files from 1k to 750-ohm (current-limits outputs to a max of 10mA, previously 8.6mA)
    [Rev0_4.brd, Rev0_4.sch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]
2014-03-14 Adds a hard reset function to the thumb joystick menu. This causes a power-cycle. -Useful for cases where the governing computer crashes during parameter transmission and Pulse Pal loops, waiting for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
    [PulsePal_0_2_final.pde, PulsePal_0_3_final.pde, PulsePal_0_4.pde]
2014-03-14 Fixes menu wrap limits for thumb joystick menu, to accomodate new reset function. Updated menu-map graphic.
    [PulsePal_0_2_final.pde, PulsePal_0_3_final.pde, PulsePal_0_4.pde]
2014-03-14 Updated reset menu text
    [PulsePal_0_2_final.pde, PulsePal_0_3_final.pde, PulsePal_0_4.pde]
2014-03-14 Replaced bipolar voltage converter in PCB design (and BOM) with a lower power, lower cost, more available part from the same family.
    [Rev0_4.brd, Rev0_4.sch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]
2014-03-26 - Set MATLAB com port auto-detect in Windows XP Home edition to throw an error - Added a dedicated COM port option to the MATLAB client (i.e. PulsePal('COM3'): tries on COM3, while PulsePal; auto-det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
    [PulsePal_0_2_final.pde, PulsePal_0_3_final.pde, PulsePal_0_4.pde]
2014-03-27 Added serial read timeout support to v0.4 firmware. Previously, if a transmission started and failed on the computer end, Pulse Pal would wait indefinitely for data. Starting with this update, Pulse 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
    [PulsePal_0_4.pde]
2014-03-31 -Cleaned up schematic (preliminary - final version will require re-routing the board)
    [Rev0_4.brd, Rev0_4.sch]
2014-04-01 Since update to CC3-0512DF-E voltage converter, schematic contained an air-wire. This is now routed. Added schematic graphic of essential circuit for reading triggers and generating outputs.
    [Rev0_4.brd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]
2014-04-02 Firmware for r0.4 devices: Added thumb joystick menu support for programming and soft-triggering the trigger channels. (Trigger channels were previously shown on the top level menu, but were inaccess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
2014-04-15 Added timeout support in firmware for r0.3 Fixed rounding bug in MATLAB single parameter update command (affects MATLAB r2009a)
    [PulsePal_0_3_final.pde]
2014-05-01 Fixed serial transmission bugs in MATLAB API, affecting transmission of custom pulse trains on OS X and Win XP
    [PulsePal_0_4.pde]
2014-05-06 Modified 0_4 firmware to achieve a ~50us improvement in post-trigger stimulus latency by skipping cycle uniformity delay loop when not actively stimulating. Latency is now 50-80us.
    [PulsePal_0_4.pde]
2014-05-14 -Fixed voltage to byte conversion in c++ and python clients -Added RestingVoltage parameter for output channels - the voltage between phases, pulses and trains (previously fixed at 0V). This change a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
    [PulsePal_0_2.pde, PulsePal_0_3.pde, PulsePal_0_4.pde]
2014-05-16 Modified firmware to use hardware timer for cycle timing. Marked reduction of cycle jitter.
    [PulsePal_0_4.pde]
2014-05-16 - Fixed bug with hard-triggering custom trains of bursts - In MATLAB client, forced monophasic pulses when sending a waveform.
    [PulsePal_0_4.pde]
2014-05-21 -Fixed a bug introduced with new hardware timing scheme in a previous update (reduces jitter in first pulse after trigger). -Fixed COM port auto-detect and GUI layout in MATLAB, for Ubuntu 14
    [PulsePal_0_2.pde, PulsePal_0_3.pde, PulsePal_0_4.pde]
2014-05-21 Added an "Op menu byte (=213)" before each serial transmission, to reduce interference from user apps that spam serial ports. This especially helps with Ubuntu 14, which spams the port by default wit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
    [PulsePal.py, PulsePalExample.py, PulsePal_0_2.pde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]
2014-05-22 -Reduced clock drift to 0.00002s / 10s with respect to NI acquisition card, by directly setting timer prescale and overflow instead of leaflabs "timer period" function (apparently broken?) -Timer no 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
    [PulsePal.py, PulsePal_0_2.pde, PulsePal_0_4.pde]
2014-06-11 Fixed bug introduced with new timing scheme - if set by thumb joystick, time values were capped at only half of their intended range. Fixed so they once again range between 100us and 3600s.
    [PulsePal_0_2.pde, PulsePal_0_3.pde, PulsePal_0_4.pde]
2014-06-18 -Changed repository name to PulsePal 1_0, reflecting the first post-beta hardware design. -Added new circuit design file for version 1.0. (Improved ground plane, removed unnecessary resistors on outp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
    [Rev1_0.brd, Rev1_0.sch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]
2014-06-18 -Updated enclosure engraving to v1.0 -Modified contour of rack mount wing
2014-07-17 Fixed firmware version - firmware now reports correct version number. Added dedicated folder with firmware used for precision and reliability measures in the Pulse Pal publication
    [PulsePal_0_3.pde, PulsePal_0_4.pde, PulsePal_1_0.pde]
2014-07-25 Removed stray trace from PCB layout
    [Rev1_0.brd]
2014-07-30 Bug fix (in firmware): When Pulse Gated or TTL Toggle mode is used to stop stimulation during a pulse (instead of an interval), the linked output channels didn't return to their resting voltages. Wit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
    [PulsePal_0_2.pde, PulsePal_0_3.pde, PulsePal_0_4.pde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]
2014-08-28 -Updated default parameters in firmware, to load when EEPROM has not been written to (on first run): Resting Voltage = 0V (was previously -10V). Only updated this for r1.0; all new devices should be 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
2014-10-27 Added GERBER files for PCB fabrication with OSH Park
2015-02-12 Removed old circuit design from CAD folder
    [Rev0_4.brd, Rev0_4.sch]
2015-03-03 Updated Maple drivers folder. The drivers folder now includes install_drivers.bat, an app that automatically installs Pulse Pal's Maple drivers in Windows 7, 8 and 8.1.

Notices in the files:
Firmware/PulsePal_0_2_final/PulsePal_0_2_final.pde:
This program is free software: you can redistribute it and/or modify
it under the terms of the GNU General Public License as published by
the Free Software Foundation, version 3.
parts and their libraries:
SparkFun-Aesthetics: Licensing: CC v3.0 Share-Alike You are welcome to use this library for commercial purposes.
